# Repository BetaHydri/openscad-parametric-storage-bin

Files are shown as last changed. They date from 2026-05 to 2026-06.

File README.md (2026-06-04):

# Parametric Open-Front Storage Bin (OpenSCAD)

A fully parametric, open-front storage bin with a low front wall and a diagonal chamfer on the side walls. Designed in [OpenSCAD](https://openscad.org/) and compatible with the **MakerWorld Parametric Maker** so you can resize it directly in the browser without installing anything.

Originally designed to organise the technical compartments of a HYMER Grand Canyon S camper, but useful anywhere you need a tidy, drop-in bin: drawers, shelves, vans, workshops, kitchens.

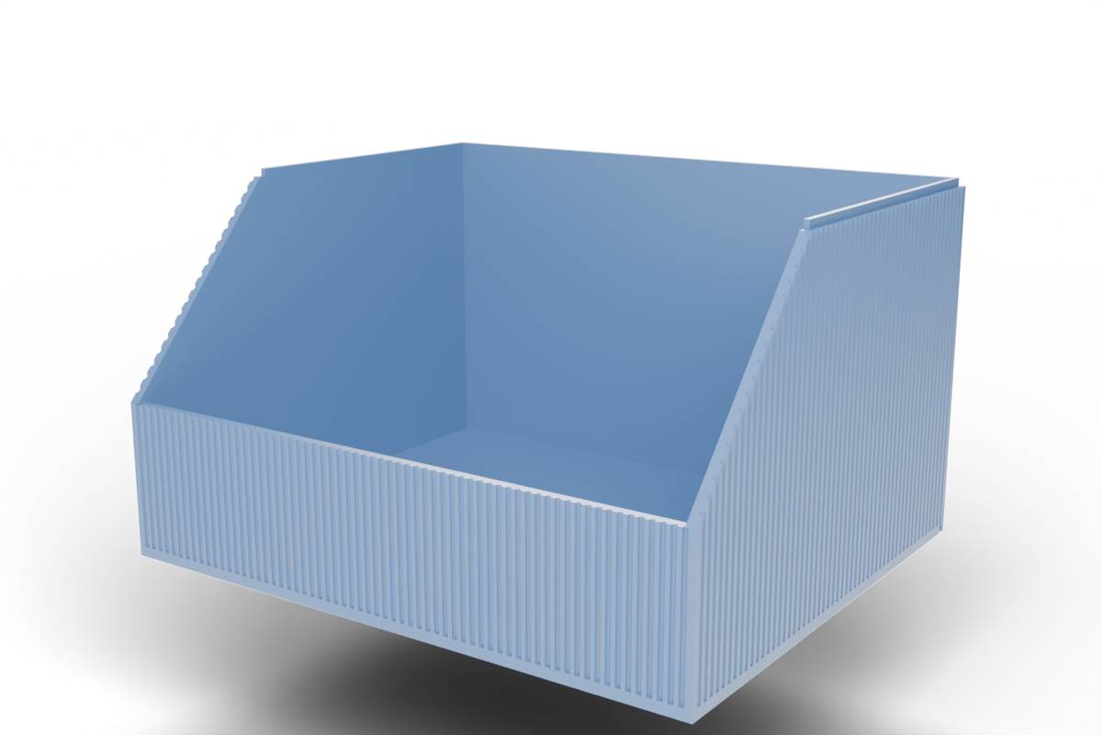
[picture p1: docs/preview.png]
Storage Bin Preview


## Print profile on MakerWorld

Ready-to-print profiles (with sliced settings) are published on MakerWorld:

**➡️ [Parametrischer offener Aufbewahrungsbehälter on MakerWorld](https://makerworld.com/de/models/2867878-parametric-open-front-storage-bin#profileId-3204005)**

You can also customise the dimensions directly on MakerWorld via the Parametric Maker — no local OpenSCAD installation required.

## Features

- Fully parametric: width, depth, height, front-wall height, chamfer length, wall and floor thickness
- Diagonal chamfer on the side walls for easy access to contents
- **Optional stacking interface** — inner lip on top mates with a recess on the bottom, so bins stack securely without sacrificing any interior volume
- **Optional relief texture** — vertical grooves on the outer walls in three styles (rectangular, V-groove, rounded), symmetrically distributed with configurable corner margin
- Optional bottom-edge chamfer to relieve elephant-foot artefacts
- Printer presets for Bambu Lab **P1S**, **P2S**, **H2C**, **H2D** (auto-clamps dimensions to the build volume) plus a **Custom** option
- Single STL — prints flat on the build plate, no supports required

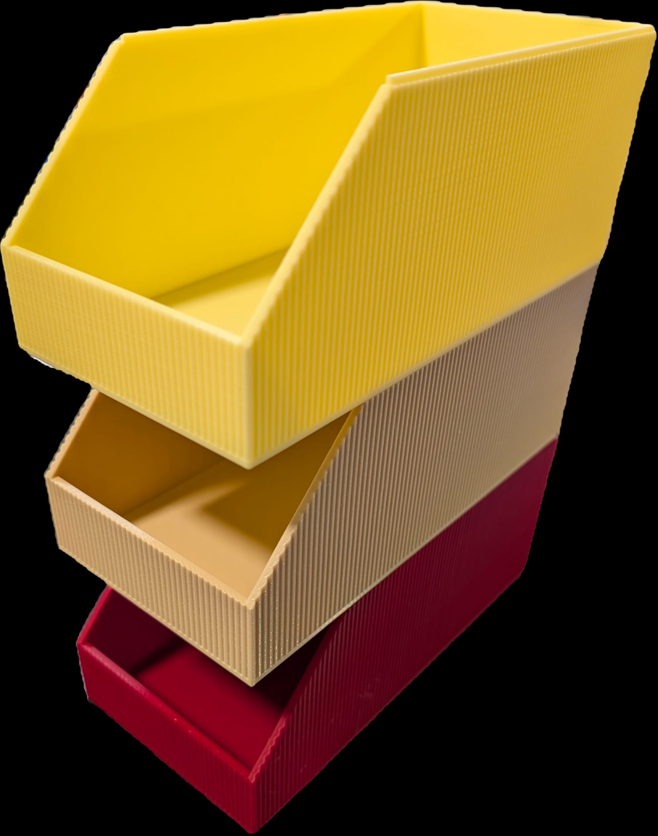
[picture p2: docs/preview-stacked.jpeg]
Stacked bins with relief texture


## Parameters

All parameters are exposed via the OpenSCAD Customizer (and the MakerWorld Parametric Maker):

| Section | Parameter | Description |
|---|---|---|
| Printer / Build Volume | `printer` | Preset: `P1S`, `P2S`, `H2C`, `H2D`, or `Custom` |
| Printer / Build Volume | `max_build_x/y/z` | Custom build volume (used only when `printer = "Custom"`) |
| Outer Dimensions | `width`, `depth`, `height` | Outer size in mm (auto-capped to build volume) |
| Front Opening | `front_height` | Height of the short front wall |
| Front Opening | `chamfer_len` | Length of the diagonal chamfer along the side walls (0 = vertical step) |
| Walls | `wall`, `floor_t` | Wall and floor thickness (auto-raised to 3.0 mm when stacking is on) |
| Stacking | `stackable` | Off (default) or On — adds a lip on top + recess on bottom so bins stack |
| Stacking | `stack_lip_h` | Height of the lip / depth of the recess (mm, default 3.0) |
| Stacking | `stack_clearance` | Horizontal fit clearance per side (mm, default 0.2) |
| Cosmetic | `bottom_chamfer` | Outer bottom-edge chamfer for elephant-foot relief |
| Relief / Texture | `relief_enabled` | Off (default) or On — adds vertical grooves on outer walls |
| Relief / Texture | `relief_style` | Groove shape: `Rectangular`, `V-groove`, or `Rounded` (default) |
| Relief / Texture | `relief_count` | Approximate total number of grooves around the full perimeter (default 240) |
| Relief / Texture | `relief_depth` | Groove depth into wall surface in mm (default 0.6) |
| Relief / Texture | `relief_width` | Groove width in mm (default 1.0) |
| Relief / Texture | `relief_corner` | Min. solid wall at each corner in mm (default 1.0) |
| Relief / Texture | `relief_walls` | Which walls: `All walls`, `Sides only`, or `Front+Back only` |
| Quality | `$fn` | Render smoothness |

Geometric inputs are clamped internally, so any combination of slider values produces a valid model.

### Stacking — how it works

Set `stackable = On` to make a bin stack with other identical-footprint bins. The geometry adds:

- A **lip** on the top of the back wall and the rear half of both side walls. The lip uses the **inner half** of the wall thickness, so the bin's outer footprint stays flat from the outside.
- A matching **U-shaped recess** in the underside of the floor (back + rear-sides).

When you stack two bins, the lip of the lower bin slots into the recess of the upper bin. **No interior storage volume is lost** — only ~`stack_lip_h` (default 3 mm) is "consumed" from the total stack height.

Notes:

- The open front means there is no lip across the front of the bin, only on the back and rear-side sections — but that's plenty for lateral stability.
- When stacking is enabled, `wall` is automatically raised to a minimum of **3.0 mm** so the half-thickness lip and recess stay structurally sound. If you set a lower value, the model auto-corrects it and logs a note to the OpenSCAD console.
- All stacked bins must have the same `width`, `depth`, `wall`, and `stack_lip_h` for the fit to work.

### Relief / Texture — how it works

Set `relief_enabled = On` to add vertical grooves on the outer wall surfaces for a decorative ribbed look.

Three groove shapes are available:

- **Rectangular** — flat-bottom channel, sharpest shadow lines, best grip
- **V-groove** — triangular notch, crisp light/shadow effect
- **Rounded** — semicircular channel, smooth premium look (default)

Grooves are distributed **symmetrically per wall** — the spacing is derived from the total perimeter count, then rounded per wall so no groove ever falls on a corner edge. The `relief_corner` parameter guarantees a minimum solid margin at every corner for structural integrity and clean printing.

> **Print note:** Groove depth is automatically clamped to leave at least 0.4 mm of wall thickness.
> All groove shapes print cleanly on FDM at 0.2 mm layer height without supports.

## Installing OpenSCAD

1. Download OpenSCAD for your platform from <https://openscad.org/downloads.html>
   - **Windows**: MSI or portable ZIP
   - **macOS**: DMG (Apple Silicon and Intel builds available)
   - **Linux**: AppImage, Snap, Flatpak, or your distro's package manager
2. Install and launch OpenSCAD.
3. Recommended: use the latest **development snapshot** — it ships a much improved Customizer and faster preview than the 2021 stable build.

## Using this model

1. Clone or download this repository:

   ```bash
   git clone https://github.com/BetaHydri/openscad-parametric-storage-bin.git
   ```

2. Open `storage-bin.scad` in OpenSCAD.
3. Open the **Customizer** panel (`Window → Customizer`) and adjust the parameters.
4. Press **F5** for a quick preview, **F6** for a full render.
5. Export the mesh: `File → Export → Export as STL…` (or `.3MF`).

## Printing

Recommended slicer settings (tested on Bambu Lab H2D with Bambu PLA Basic):

- **Layer height**: 0.20 mm
- **Walls / perimeters**: 3
- **Top / bottom layers**: 4
- **Infill**: 15 % gyroid (more if you need extra rigidity)
- **Supports**: none — the geometry is self-supporting
- **Brim**: optional; only needed for very tall/narrow bins
- **Orientation**: print flat on the build plate (floor down)

For a ready-to-print `.3mf` with profile-tuned settings, use the [MakerWorld print profile](https://makerworld.com/de/models/2867878-parametric-open-front-storage-bin#profileId-3204005).

### Bambu Studio project files

The [`print-profiles/`](print-profiles/) folder contains Bambu Studio `.3mf` project files for concrete fitments used in a HYMER Grand Canyon S camper — open them directly in Bambu Studio, re-slice if needed, and print. See [`print-profiles/README.md`](print-profiles/README.md) for details.

## License

Released under the [MIT License](LICENSE). Attribution is appreciated but not required.

## Contributing

Issues and pull requests are welcome — especially:

- Additional printer presets
- Cosmetic variants (rounded corners, dividers, label slot, magnet pockets)
- Improvements to the Customizer parameter ranges

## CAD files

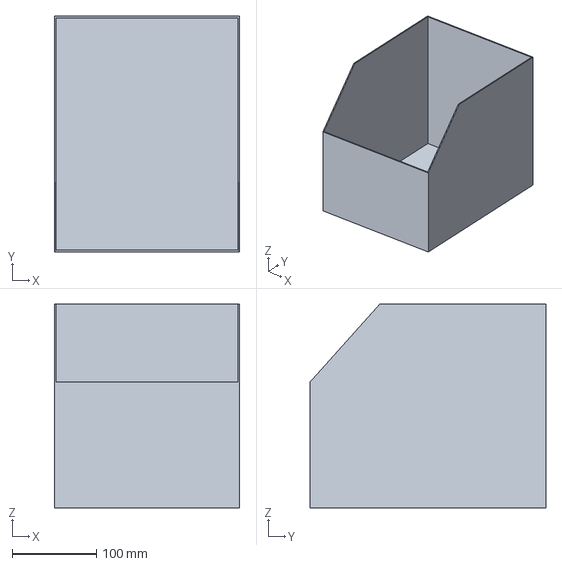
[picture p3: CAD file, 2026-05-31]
print-profiles/OberhalbGas.3mf
220.0 x 280.0 x 242.5 mm

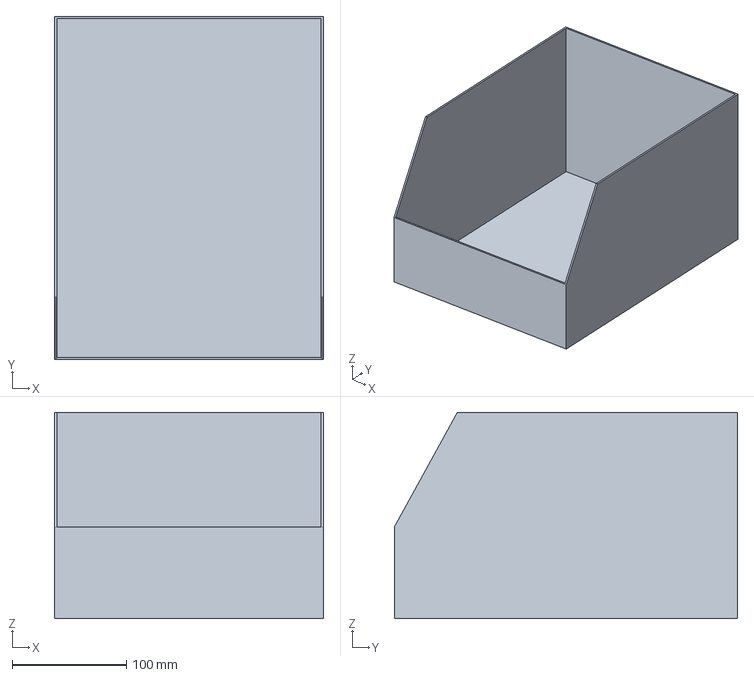
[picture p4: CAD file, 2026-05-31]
print-profiles/UntenBox.3mf
235.0 x 300.0 x 180.0 mm

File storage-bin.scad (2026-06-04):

// ============================================================
//  Parametric Open-Front Storage Bin
//  (low front wall + diagonal chamfer on side walls)
//  Units: millimetres
//  MakerWorld Parametric Maker compatible
// ============================================================

/* [Printer / Build Volume] */
// Printer preset. "Custom" uses the max_* values below; presets override them.
printer = "H2D"; // [P1S, P2S, H2C, H2D, Custom]
// Custom max build width (X) in mm — used only when printer = "Custom"
max_build_x = 350; // [100:1:500]
// Custom max build depth (Y) in mm — used only when printer = "Custom"
max_build_y = 320; // [100:1:500]
// Custom max build height (Z) in mm — used only when printer = "Custom"
max_build_z = 325; // [100:1:500]

/* [Outer Dimensions] */
// Width (left-right) in mm (auto-capped to printer build X)
width = 120;        // [40:1:500]
// Depth (front-back) in mm (auto-capped to printer build Y)
depth = 100;        // [40:1:500]
// Total height (back wall) in mm (auto-capped to printer build Z)
height = 70;        // [20:1:500]

/* [Front Opening] */
// Height of the short front wall in mm (auto-capped to height - 5)
front_height = 30;  // [5:1:495]
// Length of the diagonal chamfer on the side walls (along Y, from the front). 0 = vertical step. Auto-capped to depth - wall.
chamfer_len = 35;   // [0:1:495]

/* [Walls] */
// Side / front / back wall thickness in mm (min 3.0 when stacking is on)
wall = 2.0;         // [1.2:0.1:4.0]
// Floor thickness in mm
floor_t = 2.0;      // [1.2:0.1:4.0]

/* [Stacking] */
// Make bins stackable: adds a lip on top (back + rear sides) and a matching
// recess in the floor underside. Costs NO interior volume — only ~lip height
// of total stack height. Set to 0 to disable.
stackable = 0;          // [0:Off, 1:On]
// Height of the stacking lip / depth of the underside recess (mm)
stack_lip_h = 3.0;      // [1.0:0.1:8.0]
// Horizontal clearance between lip and recess, per side (mm). Increase for
// looser fit, decrease for tighter.
stack_clearance = 0.2;  // [0.1:0.05:0.6]

/* [Cosmetic] */
// Outer bottom edge chamfer (elephant-foot relief) in mm
bottom_chamfer = 0.6;  // [0:0.1:2.0]

/* [Relief / Texture] */
// Add vertical groove lines to the outer wall surfaces
relief_enabled = 0;         // [0:Off, 1:On]
// Groove shape: Rectangular, V-groove (triangular), or Rounded (semicircular)
relief_style = 2;           // [0:Rectangular, 1:V-groove, 2:Rounded]
// Approximate total number of grooves around the full perimeter. Per wall
// the count is rounded to the nearest integer and centered symmetrically,
// so no groove ever falls on a corner.
relief_count = 240;         // [4:1:500]
// Depth of each groove into the wall surface (mm)
relief_depth = 0.6;         // [0.2:0.1:1.2]
// Width of each groove (mm)
relief_width = 1.0;         // [0.5:0.1:4.0]
// Minimum solid wall distance from each corner (mm). Keeps corners
// structurally strong and printable.
relief_corner = 1.0;        // [1.0:0.5:15.0]
// Apply to: 0 = All walls, 1 = Sides only, 2 = Front + Back only
relief_walls = 0;           // [0:All walls, 1:Sides only, 2:Front+Back only]

/* [Quality] */
// Render smoothness ($fn). Higher = smoother but slower.
$fn = 64;           // [16:8:128]

// ============================================================
//  Printer build-volume lookup (X, Y, Z in mm)
// ============================================================
_bv =
    (printer == "P1S") ? [256, 256, 256] :
    (printer == "P2S") ? [256, 256, 256] :
    (printer == "H2C") ? [330, 320, 325] :
    (printer == "H2D") ? [350, 320, 325] :
                         [max_build_x, max_build_y, max_build_z];

_max_x = _bv[0];
_max_y = _bv[1];
_max_z = _bv[2];

// ============================================================
//  Internal clamped values
// ============================================================
_width  = min(width,  _max_x);
_depth  = min(depth,  _max_y);
_height = min(height, _max_z);

_fh = min(front_height, _height - 5);
_cl = max(0, min(chamfer_len, _depth - wall));
// Enforce minimum wall for stacking: wall/2 lip+recess need >= 1.5 mm each
_wall_raw = min(wall, min(_width, _depth) / 2 - 1);
_wall     = max(_wall_raw, stackable ? 3.0 : 0);
_floor  = min(floor_t, _height - 1);

_lip_h = max(0, min(stack_lip_h, min(_height - _fh - 1, _floor - 0.4)));

// Relief groove depth clamped to leave at least 0.4 mm of wall
_relief_depth = min(relief_depth, _wall - 0.4);

// ============================================================
//  Geometry
// ============================================================

module bin(stack=stackable, lip_h=_lip_h, clearance=stack_clearance, relief=relief_enabled) {
    difference() {
        union() {
            cube([_width, _depth, _floor]);

            translate([0, _depth - _wall, 0])
                cube([_width, _wall, _height]);

            cube([_width, _wall, _fh]);

            side_wall();

            translate([_width, 0, 0])
                mirror([1, 0, 0])
                    side_wall();
        }

        if (bottom_chamfer > 0) bottom_chamfer_cut();

        if (stack && lip_h > 0) {
            top_lip_cut(lip_h);
            bottom_recess_cut(lip_h, clearance);
        }

        if (relief && relief_count > 0) relief_grooves();
    }
}

module side_wall() {
    pts = [
        [0,      0],
        [_depth, 0],
        [_depth, _height],
        [_cl,    _height],
        [0,      _fh],
    ];

    rotate([90, 0, 90])
        linear_extrude(height = _wall)
            polygon(points = pts);
}

module bottom_chamfer_cut() {
    c = bottom_chamfer;
    translate([-0.01, -0.01, -0.01])
        rotate([0, 90, 0])
            linear_extrude(height = _width + 0.02)
                polygon([[0,0],[c,0],[0,c]]);
    translate([-0.01, _depth + 0.01, -0.01])
        rotate([0, 90, 0])
            linear_extrude(height = _width + 0.02)
                polygon([[0,0],[c,0],[0,-c]]);
    translate([-0.01, -0.01, -0.01])
        rotate([-90, 0, 90])
            linear_extrude(height = _depth + 0.02)
                polygon([[0,0],[c,0],[0,c]]);
    translate([_width + 0.01, -0.01, -0.01])
        rotate([-90, 0, 90])
            linear_extrude(height = _depth + 0.02)
                polygon([[0,0],[-c,0],[0,c]]);
}

// ----- Stacking helpers -------------------------------------
module top_lip_cut(h=_lip_h) {
    w2 = _wall / 2;
    eps = 0.01;
    translate([-eps, _depth - w2, _height - h])
        cube([_width + 2*eps, w2 + eps, h + eps]);
    translate([-eps, -eps, _height - h])
        cube([w2 + eps, _depth + 2*eps, h + eps]);
    translate([_width - w2, -eps, _height - h])
        cube([w2 + 2*eps, _depth + 2*eps, h + eps]);
    translate([w2 - eps, -eps, _height - h])
        cube([w2 + 2*eps, _cl + eps, h + eps]);
    translate([_width - _wall - eps, -eps, _height - h])
        cube([w2 + 2*eps, _cl + eps, h + eps]);
}

module bottom_recess_cut(h=_lip_h, cl=stack_clearance) {
    w2  = _wall / 2;
    eps = 0.01;
    // Back channel (full width)
    translate([-cl, _depth - _wall - cl, -eps])
        cube([_width + 2*cl, w2 + 2*cl, h + eps]);
    // Left side channel
    translate([w2 - cl, _cl - cl, -eps])
        cube([w2 + 2*cl, _depth - _cl + 2*cl, h + eps]);
    // Right side channel
    translate([_width - _wall - cl, _cl - cl, -eps])
        cube([w2 + 2*cl, _depth - _cl + 2*cl, h + eps]);
}

// ----- Relief grooves ----------------------------------------
// 2D groove cross-section centered on X=0. Opening at Y=0, depth toward -Y.
module groove_profile_2d(w, d) {
    if (relief_style == 0) {
        translate([-w/2, -d]) square([w, d]);
    } else if (relief_style == 1) {
        polygon([[-w/2, 0], [w/2, 0], [0, -d]]);
    } else {
        intersection() {
            scale([w / (2 * max(d, 0.01)), 1])
                circle(r = d, $fn = 24);
            translate([-w/2 - 0.1, -d - 0.1])
                square([w + 0.2, d + 0.1]);
        }
    }
}

// Grooves distributed per-wall, symmetrically centered.
// All grooves per wall combined into a single extrusion to keep the CSG
// tree small — avoids the "200000 elements" normalization abort.
module relief_grooves() {
    eps = 0.01;
    gd  = _relief_depth;
    gw  = relief_width;
    cm  = relief_corner;

    perim   = 2 * (_width + _depth);
    spacing = perim / max(relief_count, 1);
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

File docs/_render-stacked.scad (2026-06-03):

// Render two stacked bins for the README preview.
// Usage:
//   openscad -o docs/preview-stacked.png --imgsize=1200,800 \
//            --colorscheme=Tomorrow --camera=80,60,40,55,0,40,520 \
//            -D relief_enabled=1 \
//            docs/_render-stacked.scad

// `use` (not `include`) so we don't pull in storage-bin.scad's top-level
// `bin();` call. Relief is passed explicitly because `use` does not
// propagate the file-scope `relief_enabled` variable into `bin()`.
use <../storage-bin.scad>;

_HEIGHT = 70;
_LIP_H  = 3.0;

// Bottom bin with stacking interface and relief texture enabled
bin(stack=true, relief=true);

// Top bin lifted so the inner lip slots into the underside recess
translate([0, 0, _HEIGHT - _LIP_H])
    bin(stack=true, relief=true);

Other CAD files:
print-profiles/ObenBoxX2.gcode.3mf

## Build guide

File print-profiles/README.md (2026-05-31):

# Bambu Studio print profiles

Ready-to-use [Bambu Studio](https://bambulab.com/en/download/studio) project files (`.3mf`) for specific real-world fitments of the parametric storage bin. Open in Bambu Studio, slice, and print.

These were designed for the technical / under-seat compartments of a **HYMER Grand Canyon S** camper but are useful as concrete reference dimensions and as a starting point for your own variants.

| File | Purpose | Notes |
|---|---|---|
| `ObenBoxX2.gcode.3mf` | Upper bin (×2 plated) | Already sliced — contains G-code, ready to print on a Bambu printer |
| `OberhalbGas.3mf` | Bin above the gas locker | Project file (re-slice for your printer/filament) |
| `UntenBox.3mf` | Lower bin | Project file (re-slice for your printer/filament) |

## How to use

1. Install [Bambu Studio](https://bambulab.com/en/download/studio).
2. Double-click the `.3mf` file or open it via **File → Open Project**.
3. Adjust filament / printer profile to match your hardware if needed.
4. Re-slice (project files) or send directly (the `.gcode.3mf`).

## Generating your own variant

If your compartment dimensions differ, generate a new STL/3MF from [`../storage-bin.scad`](../storage-bin.scad) using OpenSCAD (see the [main README](../README.md)) or the [MakerWorld Parametric Maker](https://makerworld.com/de/models/2867878-parametric-open-front-storage-bin#profileId-3204005), then import the mesh into Bambu Studio.

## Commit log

2026-05-31 feat: initial parametric open-front storage bin
    [storage-bin.scad]
2026-05-31 feat(print-profiles): add Bambu Studio 3MF project files for HYMER fitments
    [ObenBoxX2.gcode.3mf, OberhalbGas.3mf, UntenBox.3mf]
2026-05-31 feat: optional stackable lip + recess with zero interior loss
    Adds stackable/stack_lip_h/stack_clearance customizer params. Inner-half lip on top of back+rear-side walls mates with a U-shaped recess in the floor underside, so stacked bins lose only ~lip height (3mm default) of total stack height -- no interior volume sacrificed. Refactors bin() to accept stack/lip_h/clearance overrides so external scripts can use it via use<>. Adds docs/_render-stacked.scad and docs/preview-stacked.png.
    [_render-stacked.scad, storage-bin.scad]
2026-05-31 fix(stackable): taper front of side-wall lip so stacked bins sit flat
    The stacking lip on each side wall ended abruptly at y=_cl where the top edge transitions into the front chamfer, leaving a vertical nose that lifted any stacked bin off the front. Add a 45-degree front taper (length = lip height) to both side-wall lips so they blend flush into the chamfered top edge. Back-wall lip and bottom recess are unchanged.
    [storage-bin.scad]
2026-05-31 fix(stackable): correct side-lip taper to cut the inner half
    The previous taper wedges were translated to the OUTER half of each side wall (x ranges already removed by the main lip cut), so they removed no material and the vertical front nose on the side lips remained. Move both wedges onto the INNER half of the wall (left: x=[w2,_wall], right: x=[_width-_wall,_width-w2]) so the lip now actually ramps from 0 at y=_cl up to full height at y=_cl+taper.
    [storage-bin.scad]
2026-05-31 fix(stackable): full-thickness 45 deg front taper on side-wall top
    Previous attempt only cut a wedge from the inner half, which dropped the inner-half top to (height - lip_h) at y=cl while the chamfer corner there is still at height - producing a new vertical step on the inner half. The outer rectangular rim cut also still started at y=cl, leaving the original outer step. Replace with a full-thickness wedge that slopes both halves from height at y=cl down to (height - lip_h) at y=cl+lip_h, and shift the outer rim rectangle to start at y=cl+lip_h. Both halves now blend smoothly into the chamfer, eliminating the nose.
    [storage-bin.scad]
2026-05-31 fix(stacking): 45 deg chamfer on lip front face
    The inner half of the side-wall lip used to start with a vertical step
    from rim level up to lip-top at y = _cl + taper, creating a sharp 'nose'
    that protruded above the rim. On a stacked pair this nose was visible
    between the bins (lower bin) and on the top surface (upper bin).
    Subtract a triangular prism from each side-wall lip front so the lip
    ramps from rim level (z = _height - h) at y = _cl + taper up to full
    lip height (z = _height) at y = _cl + taper + h. No more vertical
    nose; the chamfer line continues smoothly into the lip.
    [storage-bin.scad]
2026-05-31 fix(stacking): chop side-wall chamfer peak flat at rim level
    The side wall's chamfered top profile has its peak at (y=_cl, z=_height),
    where the diagonal from the front meets the start of the flat top. The
    previous wedge cut only sloped DOWN from that peak, leaving a sharp
    triangular point sticking up above the rim plane.
    Replace the triangular wedge with a rectangular cut from z=_height-h to
    z=_height+eps over y in [_cl, _cl+taper]. The chamfer slope now lands
    directly on the rim; no point above the stacking plane on either bin.
    [storage-bin.scad]
2026-05-31 fix(stacking): straight outer side-wall cut so bins sit flush
    The previous wedge/chamfer cuts in top_lip_cut left a triangular peak
    visible on the outer face of the side wall near the chamfer corner,
    preventing a clean flush seat when stacked.
    Replace all three side-wall cuts (outer half + full-thickness chop +
    inner-half front chamfer) with a single straight horizontal cut: the
    outer half of each side wall is sliced flat at rim level (z=_height-h)
    over the full depth y in [0, _depth]. The original chamfered profile
    in the front section is preserved wherever it sits below rim level.
    Also extend the inner-half bottom recess to span the full depth so the
    lower bin's chamfered inner side-wall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
    [storage-bin.scad]
2026-05-31 fix(stacking): shorten bottom recess to lip length
    The bottom recess previously spanned the full depth to clear the lower
    bin's chamfered inner side-wall, which left a visible slot in the floor
    running into the open-front area.
    Restrict left/right recesses to y in [_cl, _depth] (lip footprint only)
    and instead shave the INNER half of each side wall flat at rim level in
    the front chamfer region (y in [0, _cl]) inside top_lip_cut. That kills
    the small chamfer-slope poke near y=_cl that would otherwise collide
    with the upper bin's floor, while keeping the floor cosmetically clean.
    [storage-bin.scad]
2026-06-02 feat: add parametric relief/texture grooves on outer walls
    - Three groove styles: rectangular, V-groove, rounded (semicircular)
    - Symmetrical per-wall distribution with configurable corner margin
    - CSG-optimized: single extrusion per wall face
    - Disabled by default, all parameters exposed in Customizer
    - Updated README with relief documentation
    [storage-bin.scad]
2026-06-03 docs: re-render stacked preview with relief texture enabled
    [_render-stacked.scad]
2026-06-03 docs: improved Blender Cycles raytraced previews with realistic steel-blue PLA material
2026-06-03 docs: stacked preview with front-left camera showing chamfer on both bins
2026-06-03 docs: right-front camera angle matching real photo - chamfer visible on both bins
2026-06-03 docs: pull camera back ;& elevate to expose chamfer on both stacked bins
2026-06-03 docs: switch preview material to procedural wooden PLA with ground shadows
2026-06-03 feat(bin): add relief parameter to bin() for per-call relief override
    Previously the stacked preview render in docs/_render-stacked.scad could not
    enable relief on either bin because 'use<>' does not propagate the file-scope
    relief_enabled variable into the imported module. Switching to 'include<>'
    would have pulled in storage-bin.scad's top-level bin() call.
    Adds 'relief=relief_enabled' parameter to bin() so callers can opt-in
    explicitly; default behaviour is unchanged.
    [_render-stacked.scad, storage-bin.scad]
2026-06-03 docs: center stacked bins in frame + brighter warm wood tone
2026-06-04 feat(bin): enforce minimum wall thickness for stacking and log auto-adjustment
    [storage-bin.scad]
